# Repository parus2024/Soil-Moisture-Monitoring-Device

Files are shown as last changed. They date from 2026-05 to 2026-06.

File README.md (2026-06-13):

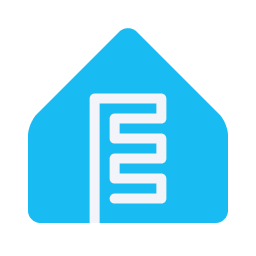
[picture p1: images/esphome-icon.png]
ESPHome Logo
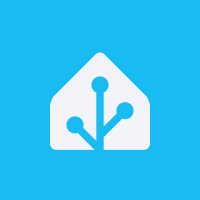
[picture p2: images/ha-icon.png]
Home Assistant Logo
 
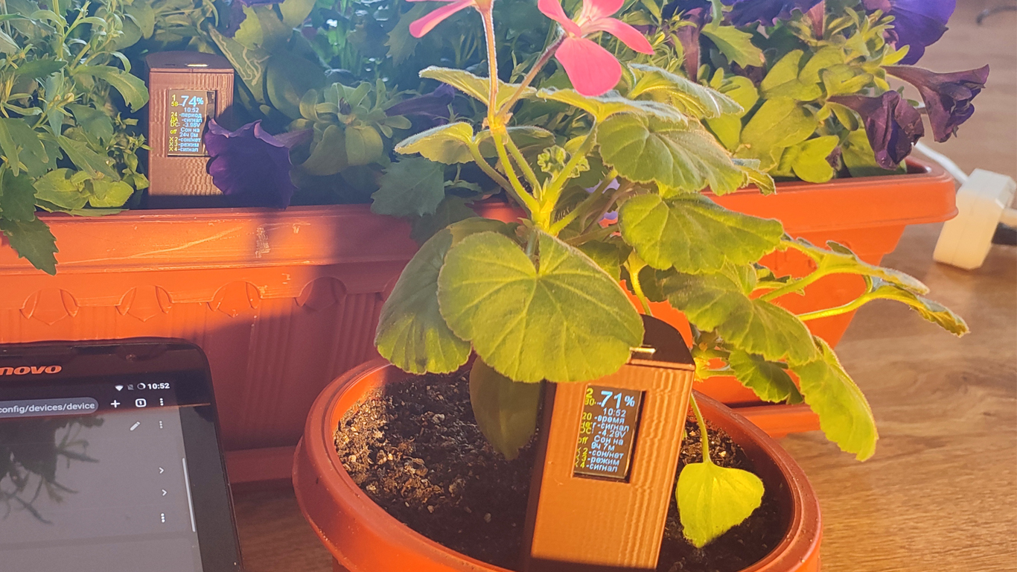
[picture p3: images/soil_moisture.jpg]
внешний вид

<p align="center">
    
    
    
    
</p>
## 🌟 Описание Проекта

# Soil-Moisture-Monitoring-Device - Устройство контроля влажности почвы
Автономное устройство контроля влажности почвы с дисплеем и оповещением, построенное на базе ESP32‑C3 и ESPHome. Устройство отслеживает влажность, отображает данные на OLED‑экране, может подавать звуковые сигналы и работать в режиме глубокого сна для экономии энергии.

## Особенности устройства и отличия от существующих.
* **Независимость.** Работоспособность не зависит от наличия сервера/хаба, от роутера и интернета.
* **Автономность.** Очень длительное время работы от аккумулятора 18650 за счёт глубокого сна.
* **OLED‑дисплей.** Отображение влажности, времени, напряжения батареи и настроек и управления.
* **Гибкие настройки.** Возможность задать уровень влажности для оповещения, период или время проверки, сигнал.
* **Многофункциональное управление.** Настройка через кнопку с короткими, двойными, тройными и т. д. нажатиями; через web -интерфейс; в Home Assistant.
* **Звуковые сигналы.** Оповещение о низком уровне влажности, разряде батареи.
* **Интеграция с Home Assistant.** Полная совместимость через API ESPHome.
* **Сохранение состояния.** Все настройки сохраняются между перезагрузками и после глубокого сна.
* **История пробуждений.** Отслеживание причин пробуждения (таймер, кнопка и т. д.).

## Основные функции

* Измерение влажности почвы с фильтрацией и калибровкой.
* Отображение данных на OLED‑дисплее в нескольких режимах (основной экран, настройки).
* Режимы работы:
    * **По периоду** (например, каждые 6 часов).
    * **По времени** (в заданные часы, например, 08:00 и 20:00).
* Оповещение звуком при влажности ниже заданного уровня.
* Управление яркостью дисплея.
* Отслеживание напряжения батареи; звуковой сигнал при напряжении ниже 3,35 В.
* Глубокий сон для экономии энергии между измерениями.
* История последних 10 пробуждений (причина и номер загрузки).

## Управление

Устройство управляется одной кнопкой:

* **Короткое нажатие:** изменение параметра на экране настроек.
* **Длительное нажатие (1,5–3 с):** вход/выход из меню настроек.
* **Двойное нажатие:** включение/выключение режима «сон/работа».
* **Тройное нажатие:** переключение между режимами «период» и «время».
* **Четверное нажатие:** включение/выключение звукового оповещения.
* **5× нажатие:** переход к настройке времени 1.
* **6× нажатие:** переход к настройке яркости.

## Экран дисплея

Основной экран отображает:
* Уровень влажности почвы (в %).
* Текущее время.
* Напряжение батареи (в В).
* Режим работы (период или время).
* Статус оповещения (ДА/нет).
* Обратный отсчёт до перехода в сон.

Меню настроек позволяет изменять:
* Период проверки (1–48 часов).
* Уровень влажности для оповещения (1–99 %).
* Время проверки 1 и 2 (часы).
* Яркость дисплея (0–100 %).

## Аппаратная часть

* **Микроконтроллер:** ESP32‑C3.
* **Дисплей:** SSD1306 (128×64), I²C.
* **Датчик влажности почвы:** HW-390, емкостной аналоговый, подключён к GPIO4.
* **Аккумулятор:** 18650 (3,7 В).
* **Зуммер:** подключён к GPIO5 для звуковых сигналов.
* **Кнопка управления:** подключена к GPIO0.
* **Измерения напряжения батареи:** подключено к GPIO1.

## Программные компоненты

* **Платформа:** ESPHome.
* **Язык конфигурации:** YAML.
* **Синхронизация времени:** SNTP (с серверами pool.ntp.org).
* **Связь:** Wi‑Fi.
* **Обновление:** OTA (Over‑The‑Air).
* **Веб‑интерфейс:** встроенный веб‑сервер для мониторинга и настройки.

## Настройка ESPHome
* Измените substitutions в начале файла под вашу конфигурацию.
* Загрузите нужные include папки (и укажите путь) или создайте свои необходимые базовые записи для ESPhome проекта.
* Загрузите шрифт `arial.ttf` в папку проекта (и укажите путь).

## 📊 Скриншоты и Видео

- [yaml файл прошивки](soil_moisture.yaml)
- [внешний вид](images/soil_moisture.jpg)
- [внешний вид](images/soil_moisture1.jpg)
- [внешний вид](images/soil_moisture4.jpg)
- [База с 5 датчиками](images/soil_moisture5.jpg)
- [Схема соединений](images/soil-moisture-shema-v1.jpeg)
- [Видео#1 YOUTUBE](https://youtu.be/_u6fvSj4mms)
- [Видео#1 RUTUBE](https://rutube.ru/video/1ed6ab72a6196f2f61acb678e1df4e1b/)
- [Файлы для печати](soil_moisture_3d/)

## 📄 Лицензия

Этот проект распространяется под лицензией MIT. Используйте на свой страх и риск.

##  Дополнительные источники информации

Телеграм канал https://t.me/parus_smart

## 🙏 Благодарности

- ESPHome сообществу за отличный фреймворк.
- Home Assistant за интеграцию.
- Вам за использование! Если проект полезен, поставьте ⭐ на GitHub.

*Создано с ❤️ ParusSmartHome. Версия: 31.05.2026*

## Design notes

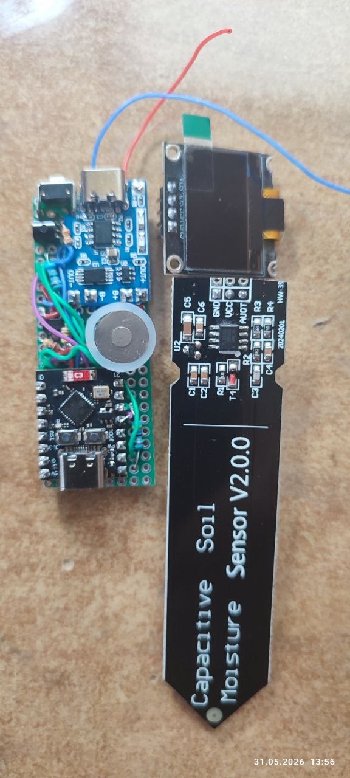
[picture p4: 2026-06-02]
images/soil_moisture3.jpg

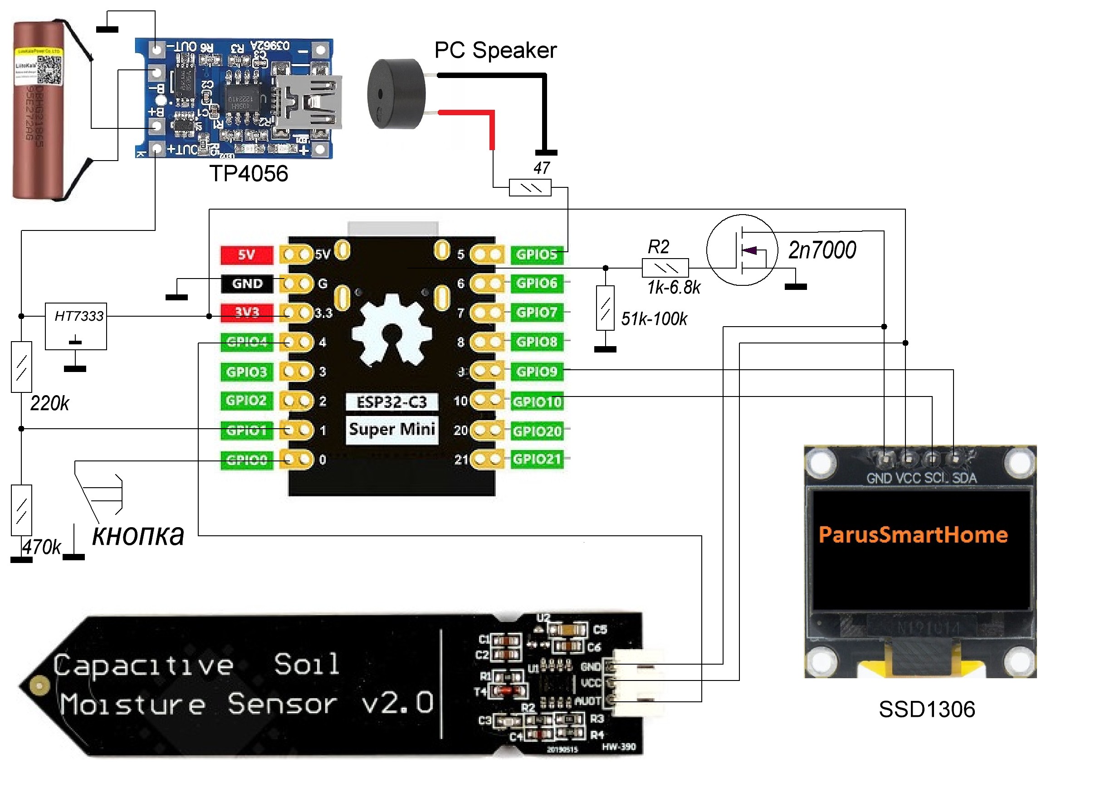
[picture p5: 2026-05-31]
images/soil-moisture-shema-v1.jpeg

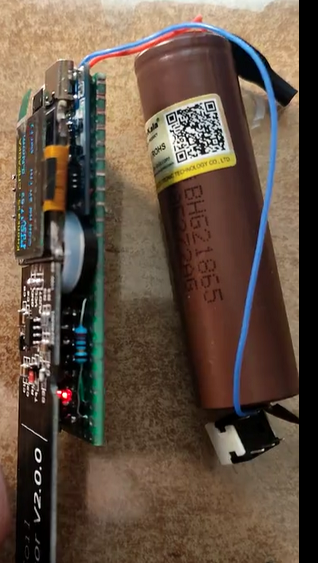
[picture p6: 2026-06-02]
images/soil_moisture1.png

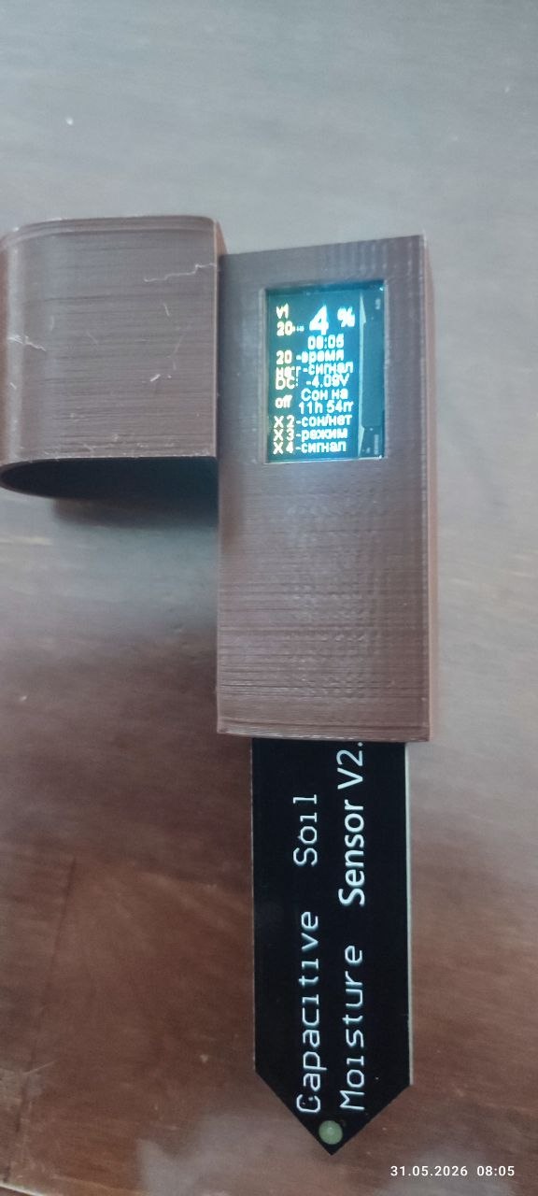
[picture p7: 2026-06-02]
images/soil_moisture4.jpg

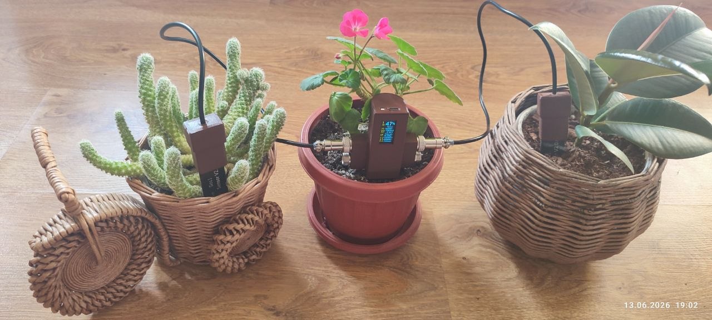
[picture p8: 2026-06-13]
images/soil_moisture5.jpg

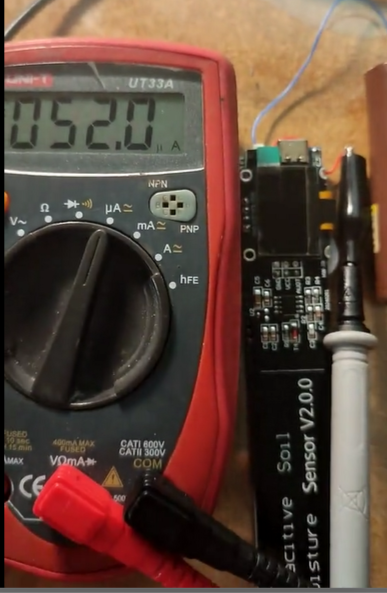
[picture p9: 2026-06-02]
images/soil_moisture2.png

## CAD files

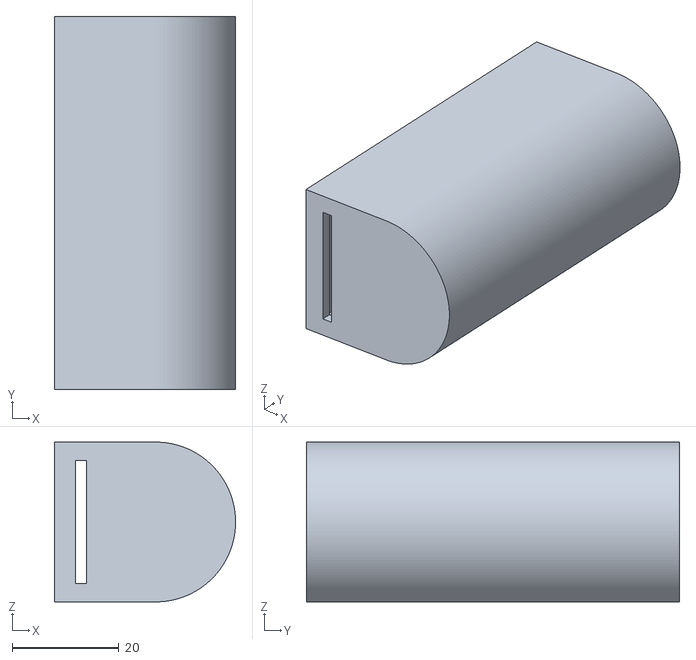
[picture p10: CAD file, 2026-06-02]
soil_moisture_3d/moisture_v1.stl
34.0 x 70.0 x 30.0

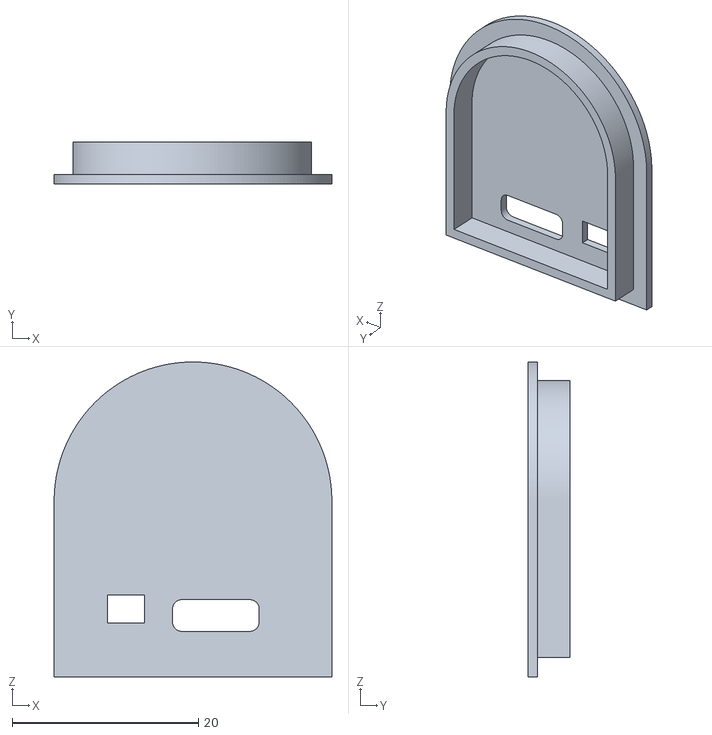
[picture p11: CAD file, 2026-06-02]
soil_moisture_3d/deck0_moisture_v1.stl
29.8 x 4.50 x 33.8

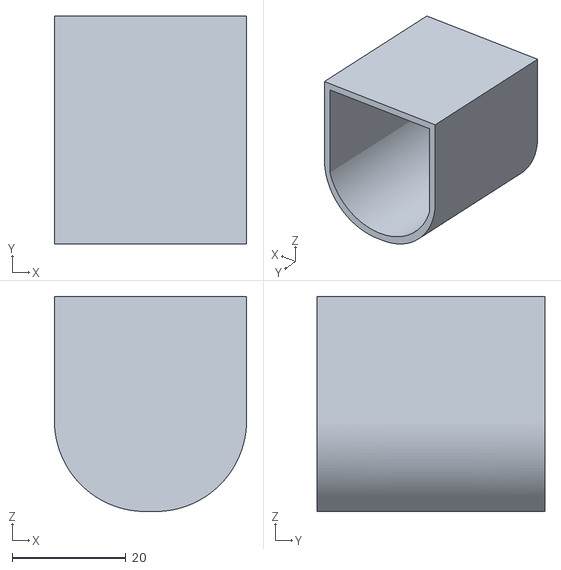
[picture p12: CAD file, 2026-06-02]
soil_moisture_3d/deck2_moisture_v1.stl
33.8 x 40.0 x 37.8

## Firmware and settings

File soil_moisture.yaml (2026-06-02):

# Board: ESP32-C3 Super Mini (Generic)
# Definition: definitions/boards/esp32-c3-supermini/manifest.yaml

substitutions:
  name: soil-moisture1
  friendly_name: Soil Moisture 1
  friendly_name_short: soil_moisture1
  version: "30.05.2026"
  device_ip: 192.168.0.170
  reboot_timeout: 0s
  button_pin: GPIO0
  batt_voltage_pin: GPIO1
  moisture_sensor_pin: GPIO4
  rtttl_pin: GPIO5
  sda1: GPIO9
  scl1: GPIO10
  run_duration: 150s
  sleep_duration: 30s

<<: !include attach/common/esphome.yaml 
<<: !include attach/common/esp/esp32_c3_idf.yaml
<<: !include attach/common/logger/debug.yaml
<<: !include attach/common/api.yaml
<<: !include attach/common/ota.yaml
<<: !include attach/common/wifi.yaml
<<: !include attach/common/web/web_server3.yaml
<<: !include attach/common/bus/i2c_a.yaml
<<: !include attach/common/sun.yaml
packages:
  common: !include attach/packages/standart.yaml
esphome:
  name: ${name}
  on_boot:
    - priority: -100
      then:
        - lambda: |-
            // Увеличиваем счётчик запусков
            id(bootCount)++;
            // Получаем причину пробуждения
            int wakeup_reason = (int)esp_sleep_get_wakeup_cause();
            // Сохраняем причину в глобальную переменную для использования в interval
            id(last_wakeup_reason) = wakeup_reason;
            // Формируем новую запись в формате "N,R"
            std::string entry = std::to_string(id(bootCount)) + "," + std::to_string(wakeup_reason);
            // Проверяем длину истории и ограничиваем до 10 записей
            const size_t max_entries = 10;
            size_t current_entries = std::count(id(bootHistory).begin(), id(bootHistory).end(), ' ') + 1;
            if (current_entries >= max_entries) {
              // Удаляем первую запись (самую старую)
              size_t pos = id(bootHistory).find(' ');
              if (pos != std::string::npos) {
                id(bootHistory) = id(bootHistory).substr(pos + 1);
              } else {
                id(bootHistory) = ""; // если нет пробелов, очищаем
              }
            }
            // Добавляем пробел, если история не пустая
            if (!id(bootHistory).empty()) {
              id(bootHistory) += " ";
            }
            // Добавляем новую запись в историю
            id(bootHistory) += entry;
            // Логи для отладки
            ESP_LOGI("boot", "Boot count: %d, Wakeup reason: %d", id(bootCount), wakeup_reason);
            ESP_LOGI("boot", "Boot history: %s", id(bootHistory).c_str());
        - text_sensor.template.publish:
            id: wakeup_cause_text
            state: !lambda |-
              switch (id(last_wakeup_reason)) {
                case 0: return {"0-Norm"};
                case 2: return {"2-EXT0"};
                case 3: return {"3-EXT1"};
                case 4: return {"4-Timer"};
                case 5: return {"5-Touchpad"};
                case 6: return {"6-ULP"};
                case 7: return {"7-GPIO"};
                case 8: return {"8-UART"};
                case 9: return {"9-WIFI"};
                case 10: return {"10-COCPU"};
                case 11: return {"11-COCPU_TRAP"};
                case 12: return {"12-BT"};
                default: return {"Unknown"};
              }
        - component.update: battery_voltage
globals:
  - id: time_received # Флаг получения времени от НА
    type: bool
    initial_value: "false"
  - id: next_sleep_duration # Переменная продолжительности сна перед засыпанием в любой момент времени
    type: uint64_t
    initial_value: '0'
  - id: bootCount # Переменная подсчета количества загрузок\выхода из сна
    type: int
    restore_value: yes
    initial_value: '0'
  - id: bootHistory # Переменная причин загрузок\выхода из сна
    type: std::string
    restore_value: yes
    initial_value: '""'
  - id: last_wakeup_reason # Переменная причины последней загрузки\выхода из сна
    type: int
    initial_value: '0' # Изначально 0 (неопределённая причина)
  - id: countdown # Обратный отсчет до сна
    type: int
    initial_value: '0'
  - id: first_event # Переменная первого события времени 1- time1 , 2-time2
    type: int
    initial_value: '0' # Изначально 0 (неопределённая причина)
  - id: long_press_active
    type: bool
    initial_value: 'false'
  - id: is_touching
    type: bool
    initial_value: 'false'
  - id: touch_start_time
    type: uint32_t
    initial_value: '0'
  - id: time1_hour_var
    type: int
    restore_value: yes
    initial_value: '8'
  - id: time2_hour_var
    type: int
    restore_value: yes
    initial_value: '20'
font:
  - file: "fonts/arial.ttf"
    id: arial_12
    size: 12
    glyphs: |-
      |#~*<>!'"%/()+=,-_.:°0123456789АБВГДЕЁЖЗИЙКЛМНОПРСТУФХЦЧШЩЬЫЪЭЮЯABCDEFGHIJKLMNOPQRSTUVWXYZ абвгдеёжзийклмнопрстуфхцчшщьыъэюяabcdefghijklmnopqrstuvwxyz
  - file: "fonts/arial.ttf"
    id: arial_20
    size: 20
    glyphs: |-
      |#~*<>!'"%/()+=,-_.:°0123456789
  - file: "fonts/arial.ttf"
    id: arial_18
    size: 18
    glyphs: |-
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

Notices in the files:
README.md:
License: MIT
